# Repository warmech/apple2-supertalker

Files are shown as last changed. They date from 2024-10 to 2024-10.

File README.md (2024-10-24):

# Supertalker - A Speech Digitizer for the Apple II

The Supertalker is a speech digitizer card for the Apple II by Mountain Computer, Inc. Originally produced in 1979 (and subsequently for the PC in the 1980s), the Supertalker is capable of digitizing and playing back speech at any of four bitrates: 0.5 KBps, 1 KBps, 2 KBps, and 4 KBps. The kit originally included a microphone and enclosed (in woodgrain, no less) speaker for use with the card.

This card is somewhat hard to find now, but I happened to come across one at a recent retrocomputing meetup for a few bucks (not knowing what it was other than some cursory googling at the time) and wanted to preserve it. The included manual and disk images are care of [apple2.org](https://mirrors.apple2.org.za/Apple%20II%20Documentation%20Project/Interface%20Cards/Speech/Mountain%20Computer%20Supertalker/).

More details to follow once initial assembly and testing are completed.

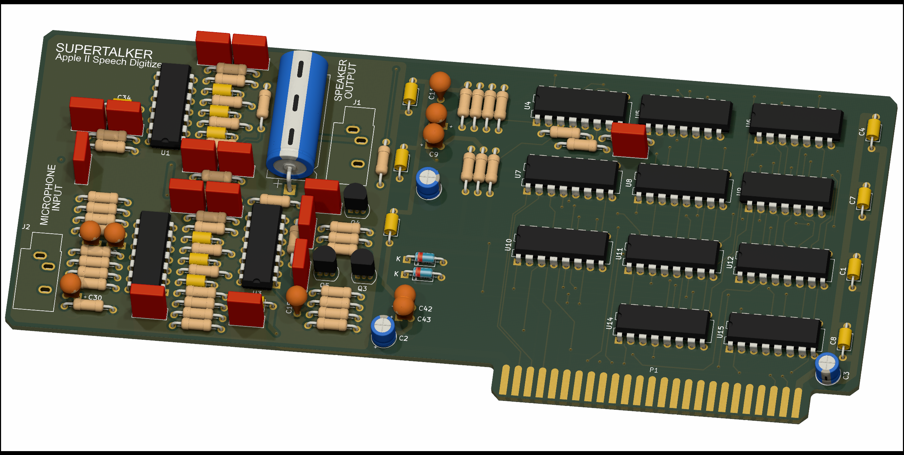
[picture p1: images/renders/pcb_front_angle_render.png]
Supertalker Front

 
## Errata

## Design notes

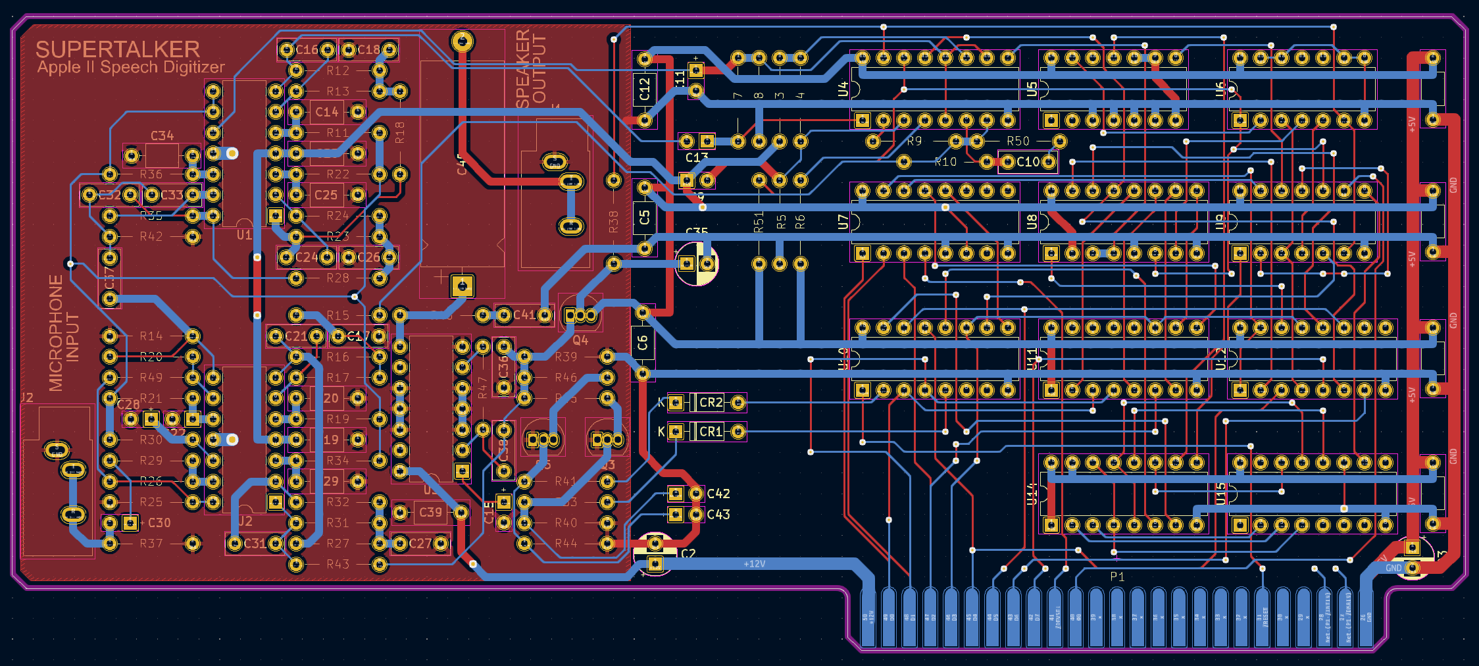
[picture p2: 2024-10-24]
images/renders/pcb_cad_view.png

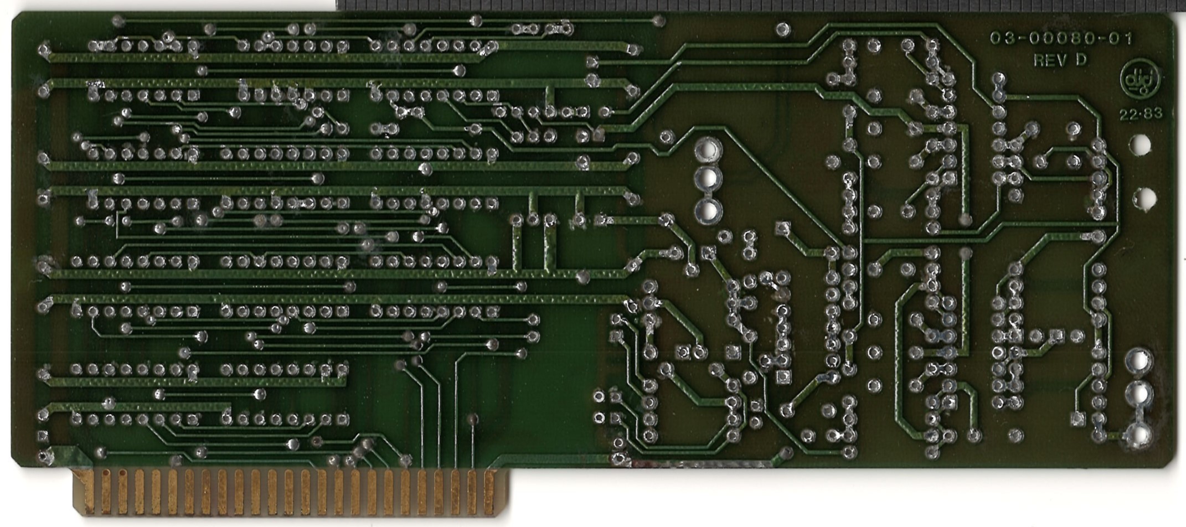
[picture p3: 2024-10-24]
images/scans/scan_back.jpg

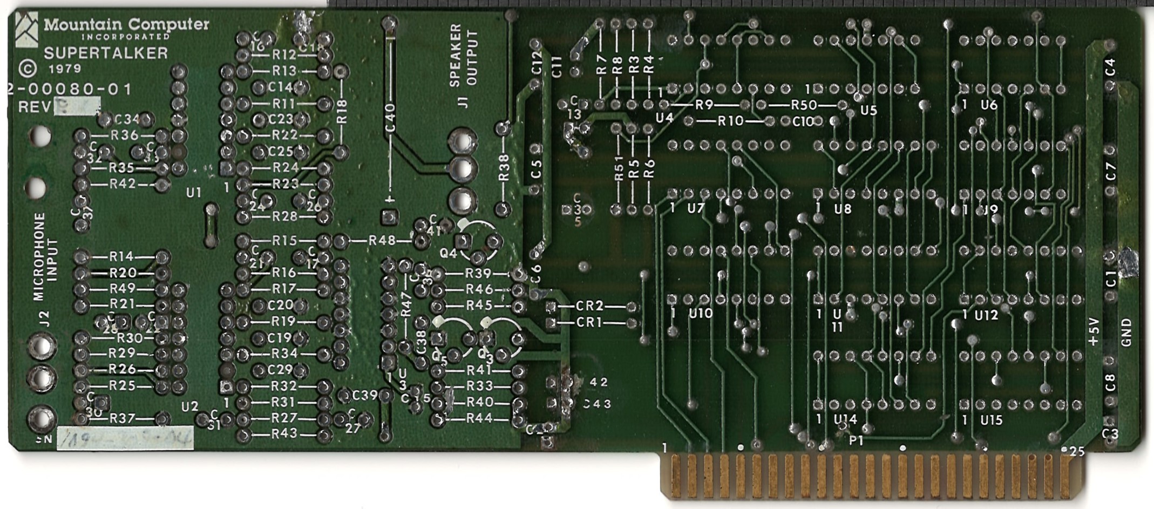
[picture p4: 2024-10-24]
images/scans/scan_front.jpg

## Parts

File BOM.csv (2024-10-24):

Item | Qty | Reference(s) | Value | LibPart | Footprint | Datasheet | DNP | Sim.Device | Sim.Pins
1 | 15 | C1, C4, C5, C6, C7, C8, C12, C14, C19, C20, C23, C25, C29, C34, C39 | 0.1uF 50V | Device:C | Capacitor_THT:C_Axial_L3.8mm_D2.6mm_P7.50mm_Horizontal | ~
2 | 3 | C2, C3, C35 | 10uF 35V | Device:C_Polarized_US | Capacitor_THT:CP_Radial_D5.0mm_P2.50mm | ~
3 | 1 | C9 | 0.39uF 50V | Device:C_Polarized_US | Capacitor_THT_Custom:CP_Radial_Tantal_D4.5mm_P2.50mm | ~
4 | 1 | C10 | 0.068uF 63V | Device:C | Capacitor_THT:C_Rect_L7.0mm_W2.5mm_P5.00mm | PolyFilm
5 | 8 | C11, C13, C15, C22, C28, C30, C42, C43 | 10uF 25V | Device:C_Polarized_US | Capacitor_THT_Custom:CP_Radial_Tantal_D4.5mm_P2.50mm | ~
6 | 2 | C16, C31 | 0.0015uF 100V | Device:C | Capacitor_THT:C_Rect_L7.0mm_W2.5mm_P5.00mm | PolyFilm
7 | 9 | C17, C18, C26, C27, C32, C33, C37, C38, C41 | 0.01uF 100V | Device:C | Capacitor_THT:C_Rect_L7.0mm_W2.5mm_P5.00mm | PolyFilm
8 | 2 | C21, C24 | 82pF 500V | Device:C | Capacitor_THT:C_Rect_L7.0mm_W2.5mm_P5.00mm | PolyFilm
9 | 1 | C36 | 100pF 500V | Device:C | Capacitor_THT:C_Rect_L7.0mm_W2.5mm_P5.00mm | PolyFilm
10 | 1 | C40 | 470uF 25V | Device:C_Polarized_US | Capacitor_THT:CP_Axial_L25.0mm_D10.0mm_P30.00mm_Horizontal | ~
11 | 2 | CR1, CR2 | 1N4148 | Diode:1N4148 | Diode_THT:D_DO-35_SOD27_P7.62mm_Horizontal | https://assets.nexperia.com/documents/data-sheet/1N4148_1N4448.pdf |  | D | 1=K 2=A
12 | 1 | J1 | SPKR OUTPUT | Connector_Audio:AudioJack3 | Connector_Audio:Jack_3.5mm_CUI_SJ1-3533NG_Horizontal | ~
13 | 1 | J2 | MIC INPUT | Connector_Audio:AudioJack3 | Connector_Audio:Jack_3.5mm_CUI_SJ1-3533NG_Horizontal | ~
14 | 1 | P1 | Apple II Expansion Bus | Connector_Custom:Apple_II_Expansion_Bus | Connector_Custom:Apple_II_Expansion_Bus_Card_Edge
15 | 3 | Q3, Q4, Q5 | PN2222A | Transistor_BJT:PN2222A | Package_TO_SOT_THT:TO-92_Inline | https://www.onsemi.com/pub/Collateral/PN2222-D.PDF
16 | 1 | R3 | 3.3K | Device:R_US | Resistor_THT_Custom:R_Axial_DIN0207_L6.3mm_D2.5mm_P10.16mm_Horizontal | ~
17 | 1 | R4 | 18K | Device:R_US | Resistor_THT_Custom:R_Axial_DIN0207_L6.3mm_D2.5mm_P10.16mm_Horizontal | ~
18 | 1 | R5 | 2.7M | Device:R_US | Resistor_THT_Custom:R_Axial_DIN0207_L6.3mm_D2.5mm_P10.16mm_Horizontal | ~
19 | 1 | R6 | 1.3K | Device:R_US | Resistor_THT_Custom:R_Axial_DIN0207_L6.3mm_D2.5mm_P10.16mm_Horizontal | ~
20 | 2 | R7, R9 | 620 | Device:R_US | Resistor_THT_Custom:R_Axial_DIN0207_L6.3mm_D2.5mm_P10.16mm_Horizontal | ~
21 | 5 | R8, R29, R37, R49, R51 | 1K | Device:R_US | Resistor_THT_Custom:R_Axial_DIN0207_L6.3mm_D2.5mm_P10.16mm_Horizontal | ~
22 | 2 | R10, R38 | 4.7K | Device:R_US | Resistor_THT_Custom:R_Axial_DIN0207_L6.3mm_D2.5mm_P10.16mm_Horizontal | ~
23 | 11 | R11, R14, R19, R21, R22, R25, R30, R33, R34, R36, R41 | 10K | Device:R_US | Resistor_THT_Custom:R_Axial_DIN0207_L6.3mm_D2.5mm_P10.16mm_Horizontal | ~
24 | 5 | R12, R18, R27, R31, R42 | 20K | Device:R_US | Resistor_THT_Custom:R_Axial_DIN0207_L6.3mm_D2.5mm_P10.16mm_Horizontal | ~
25 | 2 | R13, R32 | 33K | Device:R_US | Resistor_THT_Custom:R_Axial_DIN0207_L6.3mm_D2.5mm_P10.16mm_Horizontal | ~
26 | 4 | R15, R16, R23, R28 | 51K | Device:R_US | Resistor_THT_Custom:R_Axial_DIN0207_L6.3mm_D2.5mm_P10.16mm_Horizontal | ~
27 | 3 | R17, R24, R43 | 62K | Device:R_US | Resistor_THT_Custom:R_Axial_DIN0207_L6.3mm_D2.5mm_P10.16mm_Horizontal | ~
28 | 1 | R20 | 22K | Device:R_US | Resistor_THT_Custom:R_Axial_DIN0207_L6.3mm_D2.5mm_P10.16mm_Horizontal | ~
29 | 1 | R26 | 15K | Device:R_US | Resistor_THT_Custom:R_Axial_DIN0207_L6.3mm_D2.5mm_P10.16mm_Horizontal | ~
30 | 1 | R35 | 150K | Device:R_US | Resistor_THT_Custom:R_Axial_DIN0207_L6.3mm_D2.5mm_P10.16mm_Horizontal | ~
31 | 1 | R39 | 9.1K | Device:R_US | Resistor_THT_Custom:R_Axial_DIN0207_L6.3mm_D2.5mm_P10.16mm_Horizontal | ~
32 | 2 | R40, R44 | 6.2K | Device:R_US | Resistor_THT_Custom:R_Axial_DIN0207_L6.3mm_D2.5mm_P10.16mm_Horizontal | ~
33 | 1 | R45 | 2.2K | Device:R_US | Resistor_THT_Custom:R_Axial_DIN0207_L6.3mm_D2.5mm_P10.16mm_Horizontal | ~
34 | 1 | R46 | 6.8K | Device:R_US | Resistor_THT_Custom:R_Axial_DIN0207_L6.3mm_D2.5mm_P10.16mm_Horizontal | ~
35 | 1 | R47 | 470K | Device:R_US | Resistor_THT_Custom:R_Axial_DIN0207_L6.3mm_D2.5mm_P10.16mm_Horizontal | ~
36 | 1 | R48 | 2.7K | Device:R_US | Resistor_THT_Custom:R_Axial_DIN0207_L6.3mm_D2.5mm_P10.16mm_Horizontal | ~
37 | 1 | R50 | 68 | Device:R_US | Resistor_THT_Custom:R_Axial_DIN0207_L6.3mm_D2.5mm_P10.16mm_Horizontal | ~
38 | 2 | U1, U2 | LM324 | Amplifier_Operational:LM324 | Package_DIP:DIP-14_W7.62mm | http://www.ti.com/lit/ds/symlink/lm2902-n.pdf
39 | 1 | U3 | LM380N | Amplifier_Audio:LM380N | Package_DIP:DIP-14_W7.62mm | http://www.ti.com/lit/ds/symlink/lm380.pdf
40 | 1 | U4 | MC3418 | Interface_Custom:MC3418 | Package_DIP:DIP-16_W7.62mm
41 | 1 | U5 | 4013 | 4xxx:4013 | Package_DIP:DIP-14_W7.62mm | http://www.onsemi.com/pub/Collateral/MC14013B-D.PDF
42 | 1 | U6 | 4001 | 4xxx:4001 | Package_DIP:DIP-14_W7.62mm | http://www.intersil.com/content/dam/Intersil/documents/cd40/cd4000bms-01bms-02bms-25bms.pdf
43 | 1 | U7 | 74LS138 | 74xx:74LS138 | Package_DIP:DIP-16_W7.62mm | http://www.ti.com/lit/gpn/sn74LS138
44 | 1 | U8 | 4035 | 4xxx_Custom:4035 | Package_DIP:DIP-16_W7.62mm
45 | 1 | U9 | 74LS04 | 74xx:74LS04 | Package_DIP:DIP-14_W7.62mm | http://www.ti.com/lit/gpn/sn74LS04
46 | 1 | U10 | 74LS174 | :74LS174_1 | Package_DIP:DIP-16_W7.62mm | http://www.ti.com/lit/gpn/sn74LS174
47 | 1 | U11 | 74LS174 | 74xx:74LS174 | Package_DIP:DIP-16_W7.62mm | http://www.ti.com/lit/gpn/sn74LS174
48 | 1 | U12 | 74LS367 | :74LS367_4 | Package_DIP:DIP-16_W7.62mm
49 | 1 | U14 | 4529 | 4xxx_IEEE:4529 | Package_DIP:DIP-16_W7.62mm
50 | 1 | U15 | 4040 | 4xxx:4040 | Package_DIP:DIP-16_W7.62mm | http://www.intersil.com/content/dam/Intersil/documents/cd40/cd4020bms-24bms-40bms.pdf

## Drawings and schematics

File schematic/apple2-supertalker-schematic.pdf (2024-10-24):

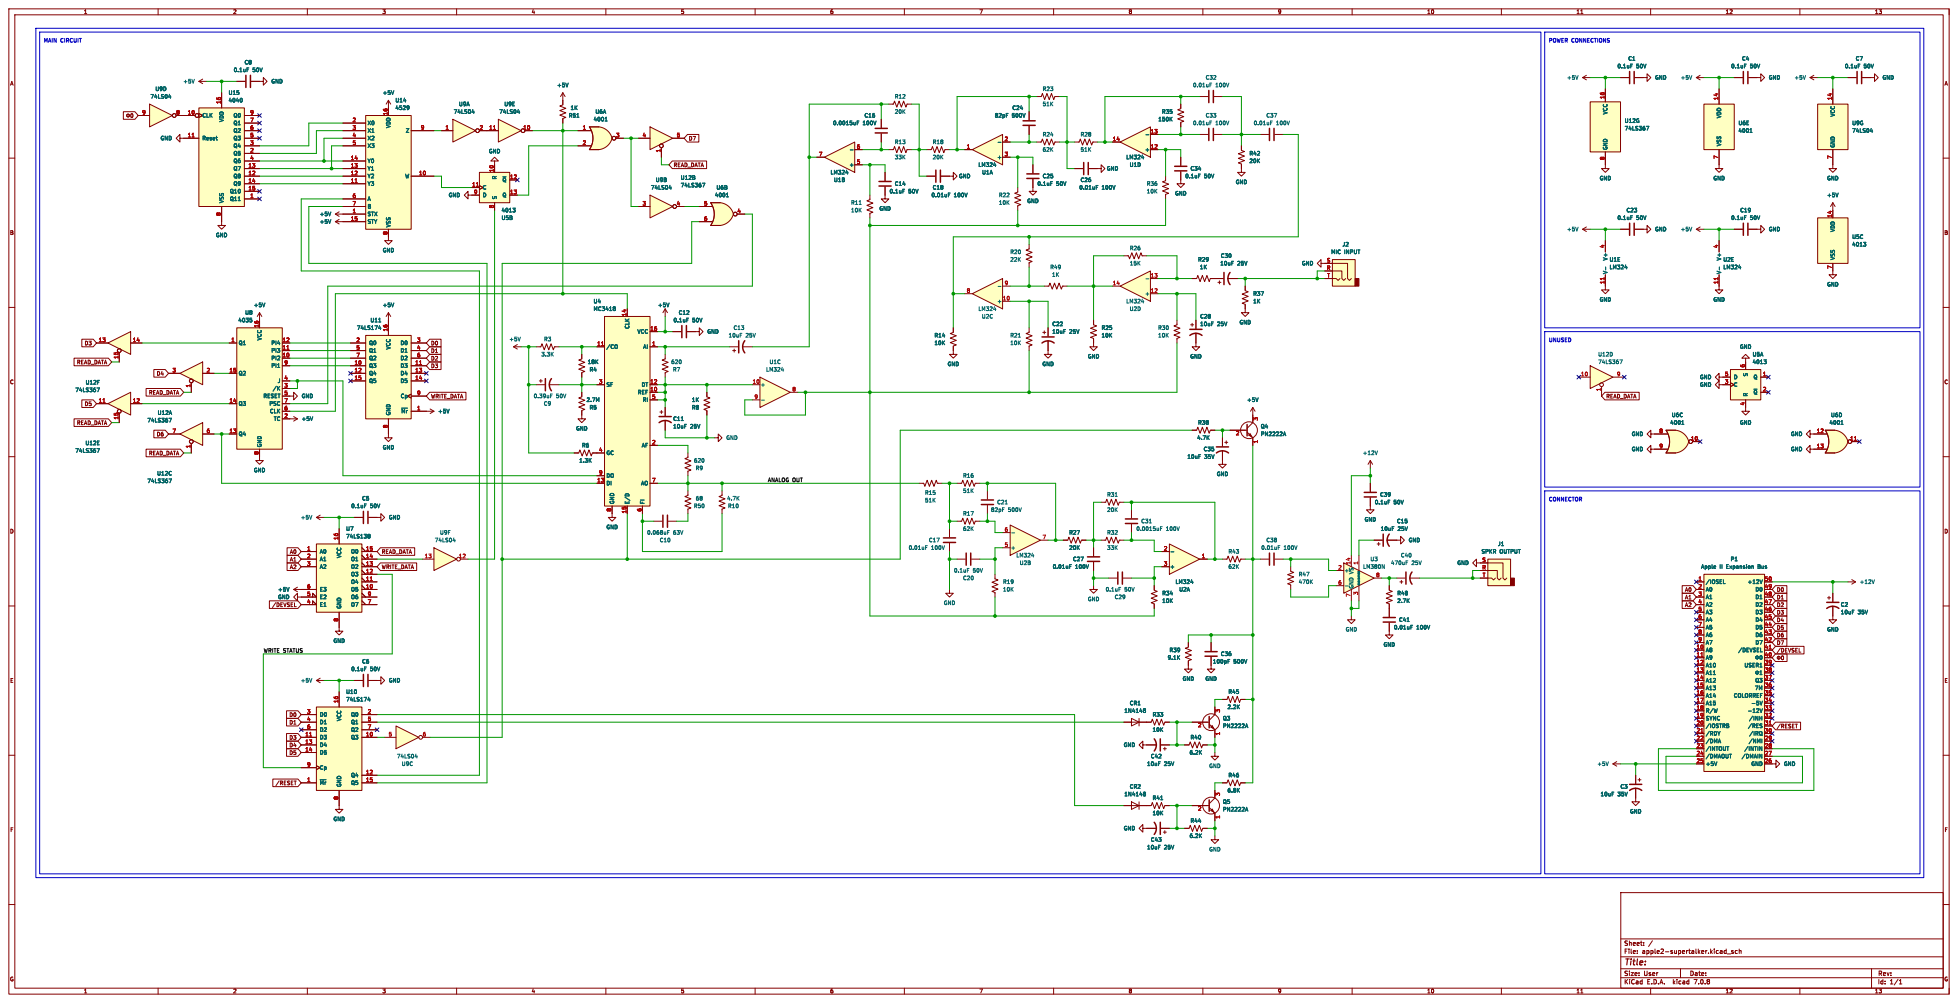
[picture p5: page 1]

J1 SPKR OUTPUT GND GND

3 Q5 PN2222A GND
Id: 1/1 Title: File: apple2-supertalker.kicad_sch Sheet: / R46

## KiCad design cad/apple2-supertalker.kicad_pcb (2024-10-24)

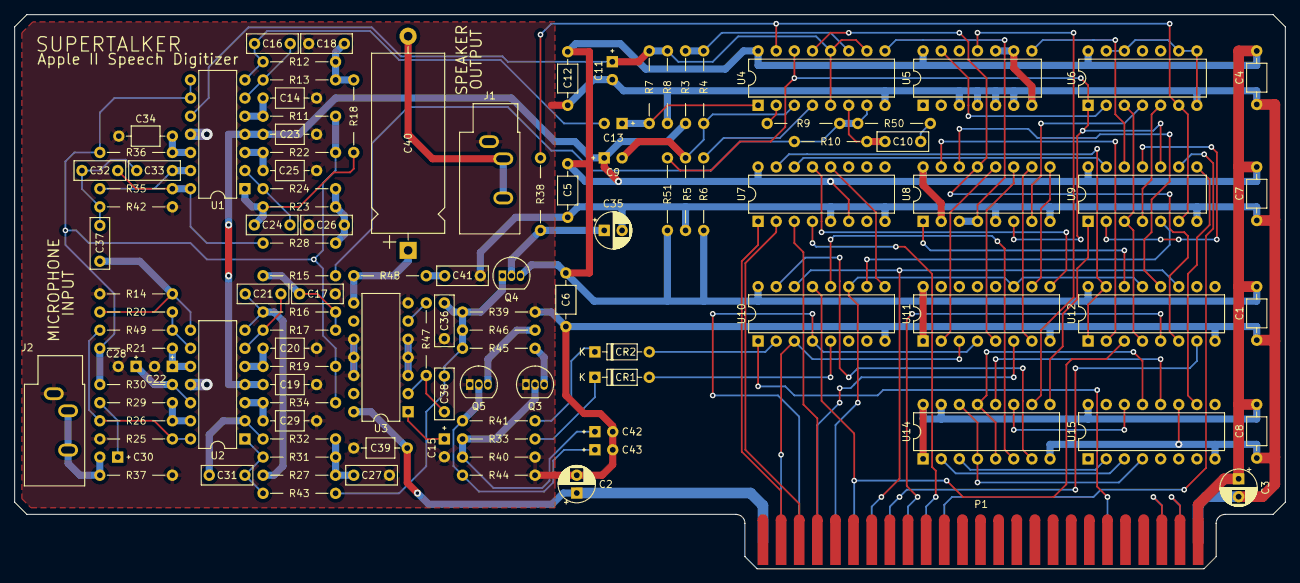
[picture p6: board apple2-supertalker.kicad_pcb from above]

Board: 2 copper layers, 178.0 x 77.6 mm, 114 parts (0 on the bottom side), 106 nets.

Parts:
C1, C4, C5, C6, C7, C8, C12, C14, C19, C20, C23, C25, C29, C34, C39: 0.1uF 50V; C_Axial_L3.8mm_D2.6mm_P7.50mm_Horizontal
C2, C3, C35: 10uF 35V; CP_Radial_D5.0mm_P2.50mm
C9: 0.39uF 50V; CP_Radial_Tantal_D4.5mm_P2.50mm
C10: 0.068uF 63V; C_Rect_L7.0mm_W2.5mm_P5.00mm
C11, C13, C15, C22, C28, C30, C42, C43: 10uF 25V; CP_Radial_Tantal_D4.5mm_P2.50mm
C16, C31: 0.0015uF 100V; C_Rect_L7.0mm_W2.5mm_P5.00mm
C17, C18, C26, C27, C32, C33, C37, C38, C41: 0.01uF 100V; C_Rect_L7.0mm_W2.5mm_P5.00mm
C21, C24: 82pF 500V; C_Rect_L7.0mm_W2.5mm_P5.00mm
C36: 100pF 500V; C_Rect_L7.0mm_W2.5mm_P5.00mm
C40: 470uF 25V; CP_Axial_L25.0mm_D10.0mm_P30.00mm_Horizontal
CR1, CR2: 1N4148; D_DO-35_SOD27_P7.62mm_Horizontal
J1: SPKR OUTPUT; Jack_3.5mm_CUI_SJ1-3533NG_Horizontal
J2: MIC INPUT; Jack_3.5mm_CUI_SJ1-3533NG_Horizontal
P1: Apple II Expansion Bus; Apple_II_Expansion_Bus_Card_Edge
Q3, Q4, Q5: PN2222A; TO-92_Inline
R3: 3.3K; R_Axial_DIN0207_L6.3mm_D2.5mm_P10.16mm_Horizontal
R4: 18K; R_Axial_DIN0207_L6.3mm_D2.5mm_P10.16mm_Horizontal
R5: 2.7M; R_Axial_DIN0207_L6.3mm_D2.5mm_P10.16mm_Horizontal
R6: 1.3K; R_Axial_DIN0207_L6.3mm_D2.5mm_P10.16mm_Horizontal
R7, R9: 620; R_Axial_DIN0207_L6.3mm_D2.5mm_P10.16mm_Horizontal
R8, R29, R37, R49, R51: 1K; R_Axial_DIN0207_L6.3mm_D2.5mm_P10.16mm_Horizontal
R10, R38: 4.7K; R_Axial_DIN0207_L6.3mm_D2.5mm_P10.16mm_Horizontal
R11, R14, R19, R21, R22, R25, R30, R33, R34, R36, R41: 10K; R_Axial_DIN0207_L6.3mm_D2.5mm_P10.16mm_Horizontal
R12, R18, R27, R31, R42: 20K; R_Axial_DIN0207_L6.3mm_D2.5mm_P10.16mm_Horizontal
R13, R32: 33K; R_Axial_DIN0207_L6.3mm_D2.5mm_P10.16mm_Horizontal
R15, R16, R23, R28: 51K; R_Axial_DIN0207_L6.3mm_D2.5mm_P10.16mm_Horizontal
R17, R24, R43: 62K; R_Axial_DIN0207_L6.3mm_D2.5mm_P10.16mm_Horizontal
R20: 22K; R_Axial_DIN0207_L6.3mm_D2.5mm_P10.16mm_Horizontal
R26: 15K; R_Axial_DIN0207_L6.3mm_D2.5mm_P10.16mm_Horizontal
R35: 150K; R_Axial_DIN0207_L6.3mm_D2.5mm_P10.16mm_Horizontal
R39: 9.1K; R_Axial_DIN0207_L6.3mm_D2.5mm_P10.16mm_Horizontal
R40, R44: 6.2K; R_Axial_DIN0207_L6.3mm_D2.5mm_P10.16mm_Horizontal
R45: 2.2K; R_Axial_DIN0207_L6.3mm_D2.5mm_P10.16mm_Horizontal
R46: 6.8K; R_Axial_DIN0207_L6.3mm_D2.5mm_P10.16mm_Horizontal
R47: 470K; R_Axial_DIN0207_L6.3mm_D2.5mm_P10.16mm_Horizontal
R48: 2.7K; R_Axial_DIN0207_L6.3mm_D2.5mm_P10.16mm_Horizontal
R50: 68; R_Axial_DIN0207_L6.3mm_D2.5mm_P10.16mm_Horizontal
U1, U2: LM324; DIP-14_W7.62mm
U3: LM380N; DIP-14_W7.62mm
U4: MC3418; DIP-16_W7.62mm
U5: 4013; DIP-14_W7.62mm
U6: 4001; DIP-14_W7.62mm
U7: 74LS138; DIP-16_W7.62mm
U8: 4035; DIP-16_W7.62mm
U9: 74LS04; DIP-14_W7.62mm
U10, U11: 74LS174; DIP-16_W7.62mm
U12: 74LS367; DIP-16_W7.62mm
U14: 4529; DIP-16_W7.62mm
U15: 4040; DIP-16_W7.62mm

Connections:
+5V: C1.2, C3.1, C4.2, C5.2, C6.2, C7.2, C8.2, C9.1, C12.2, C19.2, C23.2, P1.25 (+5V), Q4.3 (C), R3.2, R6.2, R51.2, U1.4 (V+), U2.4 (V+), U4.16 (VCC), U5.14 (VDD), U6.14 (VDD), U7.6 (E3), U7.16 (VCC), U8.2 (TC), U8.16 (VCC), U9.14 (VCC), U10.16 (VCC), U11.1 (~Mr), U11.16 (VCC), U12.16 (VCC), U14.1 (STX), U14.15 (STY), U14.16 (VDD), U15.16 (VDD)
+12V: C2.1, C39.2, P1.50 (+12V), U3.14 (VS)
/ANALOG OUT: R9.1, R10.2, R15.1, R50.2, U4.7 (AO)
/WRITE STATUS: U7.12 (O3), U10.9 (Cp)
A0: P1.2 (A0), U7.1 (A0)
A1: P1.3 (A1), U7.2 (A1)
A2: P1.4 (A2), U7.3 (A2)
D0: P1.49 (D0), U10.3 (D0), U11.3 (D0)
D1: P1.48 (D1), U10.4 (D1), U11.4 (D1)
D2: P1.47 (D2), U11.6 (D2)
D3: P1.46 (D3), U10.11 (D3), U11.11 (D3), U12.13
D4: P1.45 (D4), U10.13 (D4), U12.3
D5: P1.44 (D5), U10.14 (D5), U12.11
D6: P1.43 (D6), U12.7
D7: P1.42 (D7), U12.5
GND: C1.1, C2.2, C3.2, C4.1, C5.1, C6.1, C7.1, C8.1, C11.2, C12.1, C14.1, C15.2, C17.1, C18.1, C19.1, C20.2, C22.2, C23.1, C25.1, C26.1, C27.1, C28.2, C29.2, C34.1, C35.2, C36.1, C39.1, C41.1, C42.2, C43.2, J1.S, J2.S, P1.26 (GND), Q3.1 (E), Q5.1 (E), R5.1, R8.1, R14.2, R25.2, R37.2, R39.2, R40.2, R42.2, R44.2, U1.11 (V-), U2.11 (V-), U3.3 (GND), U3.4 (GND), U3.5 (GND), U3.7 (GND), U3.10 (GND), U3.11 (GND), U3.12 (GND), U4.8 (GND), U5.3 (C), U5.4 (R), U5.5 (D), U5.6 (S), U5.7 (VSS), U5.9 (D), U5.10 (R), U6.7 (VSS), U6.8, U6.9, U6.12, U6.13, U7.5 (E2), U7.8 (GND), U8.5 (RESET), U8.8 (GND), U9.7 (GND), U10.8 (GND), U11.8 (GND), U12.8 (GND), U14.8 (VSS), U15.8 (VSS), U15.11 (Reset)
unnamed: C10.1, R50.1
unnamed: C13.2, C16.2, R12.2, U1.7
unnamed: C17.2, R15.2, R16.1, R17.1
unnamed: C18.2, R12.1, R13.1, R18.2
unnamed: C21.2, R16.2, R27.1, U2.7
unnamed: C24.2, R18.1, R23.2, U1.1
unnamed: C26.2, R23.1, R24.1, R28.2
unnamed: C27.2, R27.2, R31.1, R32.1
unnamed: C30.1, R29.1
unnamed: C30.2, J2.R, J2.T, R37.1
unnamed: C31.2, R31.2, R43.1, U2.1
unnamed: C32.1, C33.1, C37.2, R42.1
unnamed: C32.2, R28.1, R35.1, U1.14
unnamed: C37.1, R14.1, R20.1, U2.8
unnamed: C40.1, R48.1, U3.8
unnamed: C40.2, J1.R, J1.T
unnamed: C41.2, R48.2
unnamed: CR1.2 (A), U10.5 (Q1)
unnamed: CR1.1 (K), R33.1
unnamed: CR2.2 (A), U10.2 (Q0)
unnamed: CR2.1 (K), R41.1
unnamed: P1.24 (/DMAOUT), P1.27 (/DMAIN)
unnamed: P1.23 (/INTOUT), P1.28 (/INTIN)
unnamed: C42.1, Q3.2 (B), R33.2, R40.1
unnamed: Q3.3 (C), R45.1
unnamed: C35.1, Q4.2 (B), R38.2
unnamed: C36.2, C38.2, Q4.1 (E), R39.1, R43.2, R45.2, R46.2
unnamed: C43.1, Q5.2 (B), R41.2, R44.1
unnamed: Q5.3 (C), R46.1
unnamed: R25.1, R26.2, R49.1, U2.14
unnamed: C25.2, R22.1, U1.3 (+)
unnamed: C24.1, R24.2, U1.2 (-)
unnamed: C14.2, R11.1, U1.5 (+)
unnamed: C16.1, R13.2, U1.6 (-)
unnamed: C11.1, R7.1, R8.2, U1.10 (+), U4.5 (RI), U4.10 (REF), U4.12 (DT)
unnamed: R11.2, R19.2, R21.2, R22.2, R30.2, R34.2, R36.2, U1.8, U1.9 (-)
unnamed: C34.2, R36.1, U1.12 (+)
unnamed: C33.2, R35.2, U1.13 (-)
unnamed: C29.1, R34.1, U2.3 (+)
unnamed: C31.1, R32.2, U2.2 (-)
unnamed: C20.1, R19.1, U2.5 (+)
unnamed: C21.1, R17.2, U2.6 (-)
unnamed: C22.1, R21.1, U2.10 (+)
unnamed: R20.2, R49.2, U2.9 (-)
unnamed: C28.1, R30.1, U2.12 (+)
unnamed: R26.1, R29.2, U2.13 (-)
unnamed: C38.1, R47.1, U3.2 (+)
unnamed: R47.2, U3.6 (-)
unnamed: C15.1, U3.1 (BYPASS)
unnamed: R9.2, U4.2 (AF)
unnamed: C13.1, R7.2, U4.1 (AI)
unnamed: R51.1, U4.14 (CLK), U6.1, U8.6 (CLK), U9.10
unnamed: U4.13 (DI), U8.13 (Q4), U12.6
unnamed: U4.9 (DO), U8.3 (/K), U8.4 (J)
unnamed: R38.1, U4.15 (E/D), U6.6, U9.6
unnamed: C10.2, R10.1, U4.6 (FI)
unnamed: R6.1, U4.4 (GC)
unnamed: C9.2, R4.1, R5.2, U4.3 (SF)
unnamed: R3.1, R4.2, U4.11 (/CO)
unnamed: U5.13 (Q), U6.2
unnamed: U5.8 (S), U9.12
unnamed: U6.5, U9.4
unnamed: U7.14 (O1), U9.13
unnamed: U6.4, U8.7 (PSC)
unnamed: U8.1 (Q1), U12.14
unnamed: U8.15 (Q2), U12.2
unnamed: U8.14 (Q3), U12.12
unnamed: U9.2, U9.11
unnamed: U9.5, U10.10 (Q3)
unnamed: U10.12 (Q4), U14.6 (A)
unnamed: U10.15 (Q5), U14.7 (B)
unnamed: U8.12 (PI4), U11.2 (Q0)
unnamed: U8.11 (PI3), U11.5 (Q1)
unnamed: U8.10 (PI2), U11.7 (Q2)
unnamed: U8.9 (PI1), U11.10 (Q3)
unnamed: U6.3, U9.3, U12.4
unnamed: U5.11 (C), U14.10 (W)
unnamed: U14.2 (X0), U15.3 (Q4)
unnamed: U14.3 (X1), U15.2 (Q5)
unnamed: U14.4 (X2), U14.14 (Y0), U15.4 (Q6)
unnamed: U14.5 (X3), U14.13 (Y1), U15.13 (Q7)
unnamed: U14.12 (Y2), U15.12 (Q8)
unnamed: U14.11 (Y3), U15.14 (Q9)
unnamed: U9.1, U14.9 (Z)
unnamed: U9.8, U15.10 (CLK)
READ_DATA: U7.15 (O0), U12.1, U12.15
WRITE_DATA: U7.13 (O2), U11.9 (Cp)
/DEVSEL: P1.41 (/DEVSEL), U7.4 (E1)
/RESET: P1.31 (/RES), U10.1 (~Mr)
Φ0: P1.40 (Φ0), U9.9
